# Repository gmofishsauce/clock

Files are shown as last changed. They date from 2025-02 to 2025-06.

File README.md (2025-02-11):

# Nixie tube clock with WiFi

This is a Nixie tube clock with IN-12 (axial view) Nixie tubes.
For nice packaging, the design is split into two boards. They
mount [at right angles](https://docs.google.com/presentation/d/11yNopbXGtAtQ4xKlA-b-B579JGvuL5Y8hJCB-doAy8I/edit?usp=sharing) using 96-pin Eurobus ("VME") connectors.

## Subdirectories:

- logic: logic (base board) with Arduino, drivers, power supply.
- display: display board with Nixie tube sockets
- proto: a prototype to check out the PCB footprints.

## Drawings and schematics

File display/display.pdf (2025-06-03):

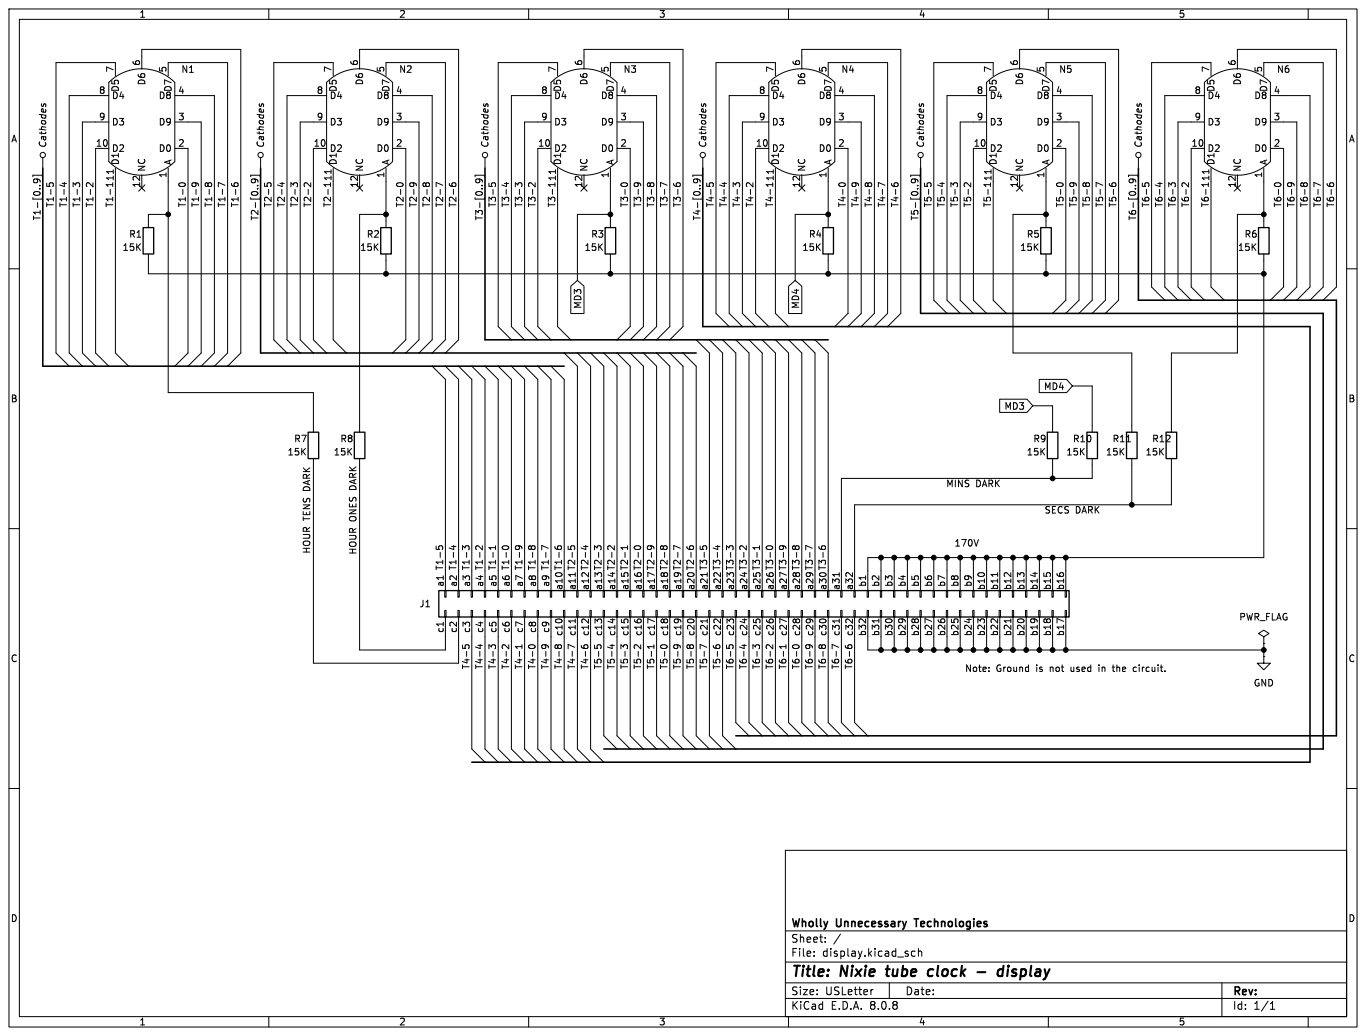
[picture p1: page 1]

Id: 1/1 Title: Nixie tube clock - display

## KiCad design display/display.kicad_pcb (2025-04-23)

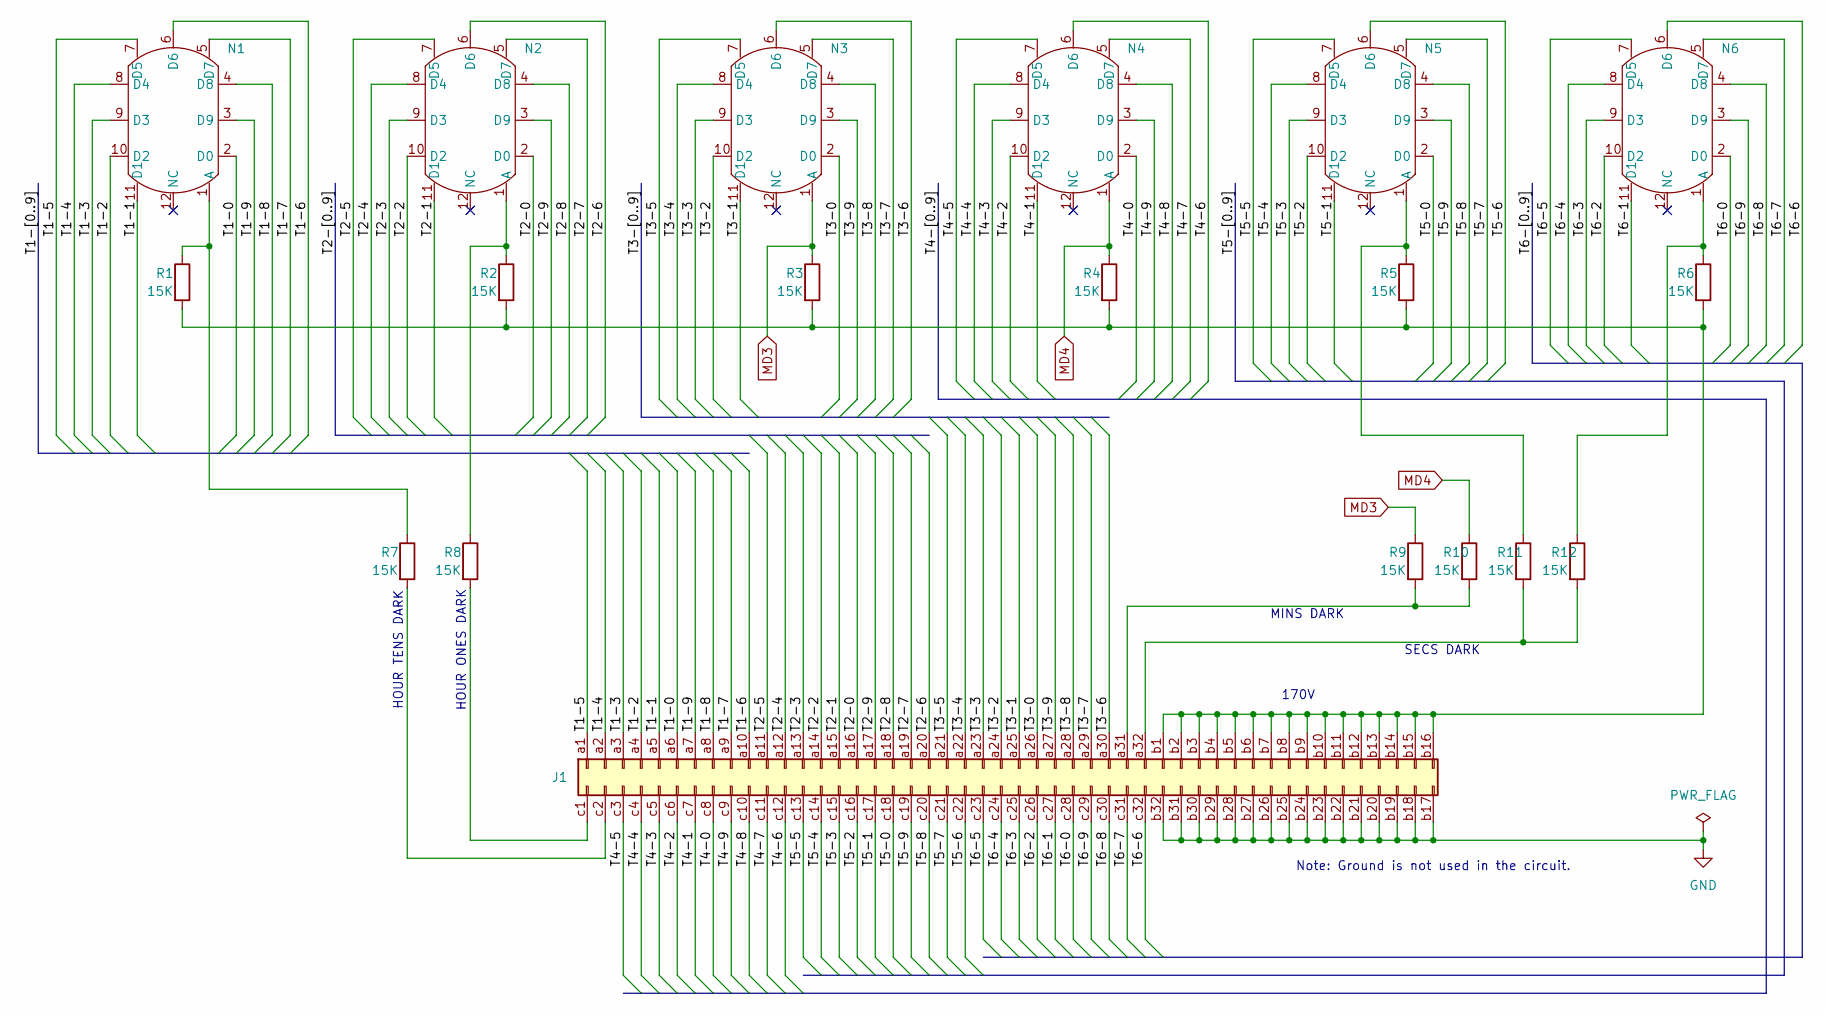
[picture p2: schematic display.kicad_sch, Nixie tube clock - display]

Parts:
J1: DIN41612_03x32_ABC; DIN41612_R_3x32_Female_Horizontal_THT
N1, N2, N3, N4, N5, N6: IN_12B_Socket
R1, R2, R3, R4, R5, R6, R7, R8, R9, R10, R11, R12: 15K; R_Box_L13.0mm_W4.0mm_P9.00mm

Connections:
/T1-0: J1.a6, N1.2 (D0)
/T1-1: J1.a5, N1.11 (D1)
/T1-2: J1.a4, N1.10 (D2)
/T1-3: J1.a3, N1.9 (D3)
/T1-4: J1.a2, N1.8 (D4)
/T1-5: J1.a1, N1.7 (D5)
/T1-6: J1.a10, N1.6 (D6)
/T1-7: J1.a9, N1.5 (D7)
/T1-8: J1.a8, N1.4 (D8)
/T1-9: J1.a7, N1.3 (D9)
/T2-0: J1.a16, N2.2 (D0)
/T2-1: J1.a15, N2.11 (D1)
/T2-2: J1.a14, N2.10 (D2)
/T2-3: J1.a13, N2.9 (D3)
/T2-4: J1.a12, N2.8 (D4)
/T2-5: J1.a11, N2.7 (D5)
/T2-6: J1.a20, N2.6 (D6)
/T2-7: J1.a19, N2.5 (D7)
/T2-8: J1.a18, N2.4 (D8)
/T2-9: J1.a17, N2.3 (D9)
/T3-0: J1.a26, N3.2 (D0)
/T3-1: J1.a25, N3.11 (D1)
/T3-2: J1.a24, N3.10 (D2)
/T3-3: J1.a23, N3.9 (D3)
/T3-4: J1.a22, N3.8 (D4)
/T3-5: J1.a21, N3.7 (D5)
/T3-6: J1.a30, N3.6 (D6)
/T3-7: J1.a29, N3.5 (D7)
/T3-8: J1.a28, N3.4 (D8)
/T3-9: J1.a27, N3.3 (D9)
/T4-0: J1.c8, N4.2 (D0)
/T4-1: J1.c7, N4.11 (D1)
/T4-2: J1.c6, N4.10 (D2)
/T4-3: J1.c5, N4.9 (D3)
/T4-4: J1.c4, N4.8 (D4)
/T4-5: J1.c3, N4.7 (D5)
/T4-6: J1.c12, N4.6 (D6)
/T4-7: J1.c11, N4.5 (D7)
/T4-8: J1.c10, N4.4 (D8)
/T4-9: J1.c9, N4.3 (D9)
/T5-0: J1.c18, N5.2 (D0)
/T5-1: J1.c17, N5.11 (D1)
/T5-2: J1.c16, N5.10 (D2)
/T5-3: J1.c15, N5.9 (D3)
/T5-4: J1.c14, N5.8 (D4)
/T5-5: J1.c13, N5.7 (D5)
/T5-6: J1.c22, N5.6 (D6)
/T5-7: J1.c21, N5.5 (D7)
/T5-8: J1.c20, N5.4 (D8)
/T5-9: J1.c19, N5.3 (D9)
/T6-0: J1.c28, N6.2 (D0)
/T6-1: J1.c27, N6.11 (D1)
/T6-2: J1.c26, N6.10 (D2)
/T6-3: J1.c25, N6.9 (D3)
/T6-4: J1.c24, N6.8 (D4)
/T6-5: J1.c23, N6.7 (D5)
/T6-6: J1.c32, N6.6 (D6)
/T6-7: J1.c31, N6.5 (D7)
/T6-8: J1.c30, N6.4 (D8)
/T6-9: J1.c29, N6.3 (D9)
GND: J1.b17, J1.b18, J1.b19, J1.b20, J1.b21, J1.b22, J1.b23, J1.b24, J1.b25, J1.b26, J1.b27, J1.b28, J1.b29, J1.b30, J1.b31, J1.b32
MD3: N3.1 (A), R3.1, R9.1
MD4: N4.1 (A), R4.1, R10.1
unnamed: J1.a31, R9.2, R10.2
unnamed: J1.a32, R11.2, R12.2
unnamed: J1.b1, J1.b2, J1.b3, J1.b4, J1.b5, J1.b6, J1.b7, J1.b8, J1.b9, J1.b10, J1.b11, J1.b12, J1.b13, J1.b14, J1.b15, J1.b16, R1.2, R2.2, R3.2, R4.2, R5.2, R6.2
unnamed: J1.c1, R8.2
unnamed: J1.c2, R7.2
unnamed: N1.1 (A), R1.1, R7.1
unnamed: N2.1 (A), R2.1, R8.1
unnamed: N5.1 (A), R5.1, R11.1
unnamed: N6.1 (A), R6.1, R12.1

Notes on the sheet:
Note: Ground is not used in the circuit.
MINS DARK
SECS DARK
HOUR ONES DARK
170V
HOUR TENS DARK

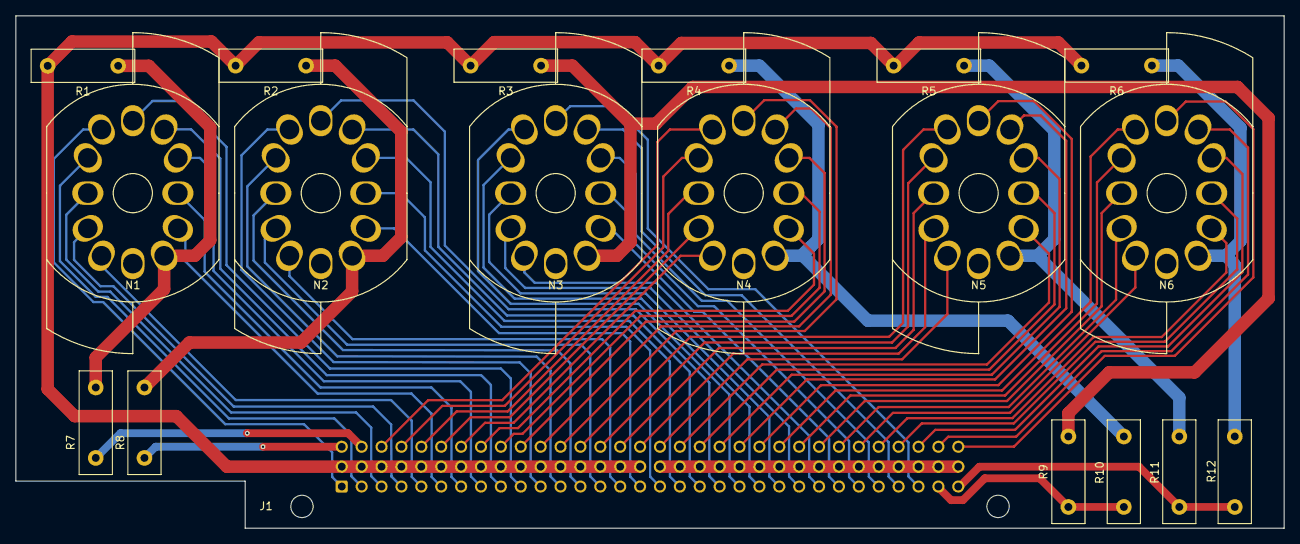
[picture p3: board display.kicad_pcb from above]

Board: 4 copper layers, 162.0 x 65.4 mm, 19 parts (1 on the bottom side), 72 nets.

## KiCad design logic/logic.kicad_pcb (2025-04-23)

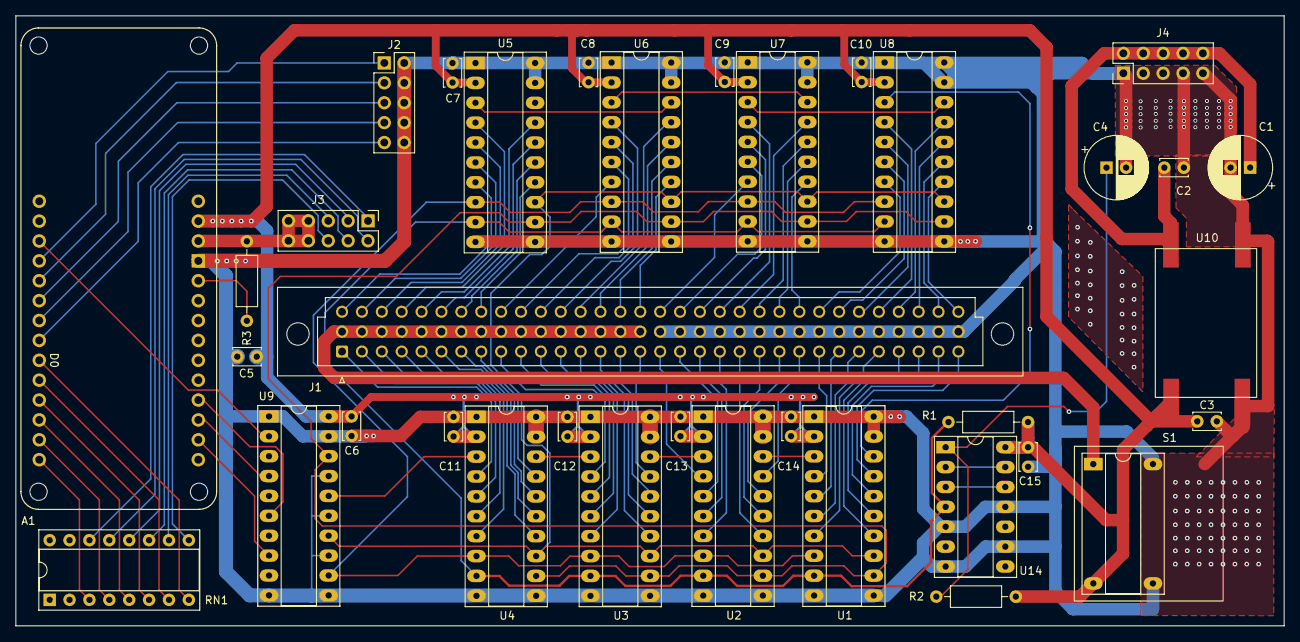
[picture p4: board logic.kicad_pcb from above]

Board: 4 copper layers, 162.0 x 77.9 mm, 36 parts (0 on the bottom side), 106 nets.

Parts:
A1: Arduino_MKR_WiFi_1010_Socket
C1, C4: C; CP_Radial_D8.0mm_P2.50mm
C2, C3, C5, C6, C7, C8, C9, C10, C11, C12, C13, C14, C15: C; C_Disc_D3.4mm_W2.1mm_P2.50mm
J1: DIN41612_03x32_ABC; DIN41612_R_3x32_Male_Vertical_THT
J2, J3, J4: Conn_02x05_Odd_Even; PinHeader_2x05_P2.54mm_Vertical
R1, R2, R3: R; R_Axial_DIN0207_L6.3mm_D2.5mm_P10.16mm_Horizontal
RN1: R_Pack08; DIP-16_W7.62mm_Socket
S1: NCH8200HV
U1, U2, U3, U4, U5, U6, U7, U8: TPIC6595; DIP-20_W7.62mm_Socket_LongPads
U9: 74HCT244; DIP-20_W7.62mm_Socket_LongPads
U10: TR4R7
U14: 74HC14; DIP-14_W7.62mm_Socket_LongPads

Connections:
/B1-0: J1.a25, U1.4 (DRAIN0)
/B1-1: J1.a26, U1.5 (DRAIN1)
/B1-2: J1.a27, U1.6 (DRAIN2)
/B1-3: J1.a28, U1.7 (DRAIN3)
/B1-4: J1.a29, U1.14 (DRAIN4)
/B1-5: J1.a30, U1.15 (DRAIN5)
/B1-6: J1.a31, U1.16 (DRAIN6)
/B1-7: J1.a32, U1.17 (DRAIN7)
/B2-0: J1.a17, U2.4 (DRAIN0)
/B2-1: J1.a18, U2.5 (DRAIN1)
/B2-2: J1.a19, U2.6 (DRAIN2)
/B2-3: J1.a20, U2.7 (DRAIN3)
/B2-4: J1.a21, U2.14 (DRAIN4)
/B2-5: J1.a22, U2.15 (DRAIN5)
/B2-6: J1.a23, U2.16 (DRAIN6)
/B2-7: J1.a24, U2.17 (DRAIN7)
/B3-0: J1.a9, U3.4 (DRAIN0)
/B3-1: J1.a10, U3.5 (DRAIN1)
/B3-2: J1.a11, U3.6 (DRAIN2)
/B3-3: J1.a12, U3.7 (DRAIN3)
/B3-4: J1.a13, U3.14 (DRAIN4)
/B3-5: J1.a14, U3.15 (DRAIN5)
/B3-6: J1.a15, U3.16 (DRAIN6)
/B3-7: J1.a16, U3.17 (DRAIN7)
/B4-0: J1.a1, U4.4 (DRAIN0)
/B4-1: J1.a2, U4.5 (DRAIN1)
/B4-2: J1.a3, U4.6 (DRAIN2)
/B4-3: J1.a4, U4.7 (DRAIN3)
/B4-4: J1.a5, U4.14 (DRAIN4)
/B4-5: J1.a6, U4.15 (DRAIN5)
/B4-6: J1.a7, U4.16 (DRAIN6)
/B4-7: J1.a8, U4.17 (DRAIN7)
/B5-0: J1.c1, U5.7 (DRAIN3)
/B5-1: J1.c2, U5.6 (DRAIN2)
/B5-2: J1.c3, U5.5 (DRAIN1)
/B5-3: J1.c4, U5.4 (DRAIN0)
/B5-4: J1.c5, U5.17 (DRAIN7)
/B5-5: J1.c6, U5.16 (DRAIN6)
/B5-6: J1.c7, U5.15 (DRAIN5)
/B5-7: J1.c8, U5.14 (DRAIN4)
/B6-0: J1.c9, U6.7 (DRAIN3)
/B6-1: J1.c10, U6.6 (DRAIN2)
/B6-2: J1.c11, U6.5 (DRAIN1)
/B6-3: J1.c12, U6.4 (DRAIN0)
/B6-4: J1.c13, U6.17 (DRAIN7)
/B6-5: J1.c14, U6.16 (DRAIN6)
/B6-6: J1.c15, U6.15 (DRAIN5)
/B6-7: J1.c16, U6.14 (DRAIN4)
/B7-0: J1.c17, U7.7 (DRAIN3)
/B7-1: J1.c18, U7.6 (DRAIN2)
/B7-2: J1.c19, U7.5 (DRAIN1)
/B7-3: J1.c20, U7.4 (DRAIN0)
/B7-4: J1.c21, U7.17 (DRAIN7)
/B7-5: J1.c22, U7.16 (DRAIN6)
/B7-6: J1.c23, U7.15 (DRAIN5)
/B7-7: J1.c24, U7.14 (DRAIN4)
/B8-0: J1.c25, U8.7 (DRAIN3)
/B8-1: J1.c26, U8.6 (DRAIN2)
/B8-2: J1.c27, U8.5 (DRAIN1)
/B8-3: J1.c28, U8.4 (DRAIN0)
/B8-4: J1.c29, U8.17 (DRAIN7)
/B8-5: J1.c30, U8.16 (DRAIN6)
/B8-6: J1.c31, U8.15 (DRAIN5)
/B8-7: J1.c32, U8.14 (DRAIN4)
/RCLK: U1.12 (RCLK), U2.12 (RCLK), U3.12 (RCLK), U4.12 (RCLK), U5.12 (RCLK), U6.12 (RCLK), U7.12 (RCLK), U8.12 (RCLK), U9.18 (O0a)
/SRCK: U1.13 (SRCK), U2.13 (SRCK), U3.13 (SRCK), U4.13 (SRCK), U5.13 (SRCK), U6.13 (SRCK), U7.13 (SRCK), U8.13 (SRCK), U9.14 (O2a)
/Sin1: U1.3 (SER_IN), U2.18 (SER_OUT)
/Sin2: U2.3 (SER_IN), U3.18 (SER_OUT)
/Sin3: U3.3 (SER_IN), U4.18 (SER_OUT)
/Sin4: U4.3 (SER_IN), U9.16 (O1a)
/Sin5: U5.3 (SER_IN), U6.18 (SER_OUT)
/Sin6: U6.3 (SER_IN), U7.18 (SER_OUT)
/Sin7: U7.3 (SER_IN), U8.18 (SER_OUT)
/Sin8: U1.18 (SER_OUT), U8.3 (SER_IN)
/~SRCLR3.3: A1.A1, U9.2 (I0a)
/~SRCLR: U1.8 (~SRCLR), U2.8 (~SRCLR), U3.8 (~SRCLR), U4.8 (~SRCLR), U5.8 (~SRCLR), U6.8 (~SRCLR), U7.8 (~SRCLR), U8.8 (~SRCLR), U9.12 (O3a)
GND: A1.GND, C1.2, C2.2, C3.2, C4.2, C5.2, C6.2, C7.2, C8.2, C9.2, C10.2, C11.2, C12.2, C13.2, C14.2, C15.2, J1.b17, J1.b18, J1.b19, J1.b20, J1.b21, J1.b22, J1.b23, J1.b24, J1.b25, J1.b26, J1.b27, J1.b28, J1.b29, J1.b30, J1.b31, J1.b32, J2.2, J2.4, J2.6, J2.8, J2.10, J4.1, J4.3, J4.5, J4.7, J4.9, S1.3 (LGND), S1.4 (PGND), U1.1 (PGND), U1.10 (PGND), U1.11 (PGND), U1.19 (LGND), U1.20 (PGND), U2.1 (PGND), U2.10 (PGND), U2.11 (PGND), U2.19 (LGND), U2.20 (PGND), U3.1 (PGND), U3.10 (PGND), U3.11 (PGND), U3.19 (LGND), U3.20 (PGND), U4.1 (PGND), U4.10 (PGND), U4.11 (PGND), U4.19 (LGND), U4.20 (PGND), U5.1 (PGND), U5.10 (PGND), U5.11 (PGND), U5.19 (LGND), U5.20 (PGND), U6.1 (PGND), U6.10 (PGND), U6.11 (PGND), U6.19 (LGND), U6.20 (PGND), U7.1 (PGND), U7.10 (PGND), U7.11 (PGND), U7.19 (LGND), U7.20 (PGND), U8.1 (PGND), U8.10 (PGND), U8.11 (PGND), U8.19 (LGND), U8.20 (PGND), U9.1 (OEa), U9.10 (GND), U9.11 (I0b), U9.13 (I1b), U9.15 (I2b), U9.17 (I3b), U9.19 (OEb), U10.3 (GND), U10.4 (IN-), U14.5, U14.7 (GND), U14.9, U14.11
unnamed: A1.D8 (D8_MOSI), U9.4 (I1a)
unnamed: A1.D9 (D9_SCK), U9.6 (I2a)
unnamed: A1.RST (RESET), R3.2
unnamed: C4.1, R2.2, U14.1
unnamed: A1.A2, J2.1
unnamed: A1.A3, J2.3
unnamed: A1.A4, J2.5
unnamed: A1.A5, J2.7
unnamed: A1.A6, J2.9
unnamed: J3.1, RN1.14 (R3.2)
unnamed: J3.2, RN1.13 (R4.2)
unnamed: J3.3, RN1.12 (R5.2)
unnamed: J3.4, RN1.11 (R6.2)
unnamed: J3.5, RN1.10 (R7.2)
unnamed: J3.6, RN1.9 (R8.2)
unnamed: C1.1, C2.1, J4.2, J4.4, J4.6, J4.8, J4.10, U10.1 (IN+)
unnamed: A1.D5, RN1.3 (R3.1)
unnamed: A1.D4, RN1.4 (R4.1)
unnamed: A1.D3, RN1.5 (R5.1)
unnamed: A1.D2, RN1.6 (R6.1)
unnamed: A1.D1, RN1.7 (R7.1)
unnamed: A1.D0, RN1.8 (R8.1)
unnamed: A1.D7, U9.8 (I3a)
unnamed: U14.3, U14.12
unnamed: U14.2, U14.13
POR: R1.2, U1.9 (~G), U2.9 (~G), U3.9 (~G), U4.9 (~G), U5.9 (~G), U6.9 (~G), U7.9 (~G), U8.9 (~G), U14.4
V3.3: A1.3V3 (3.3V), J3.7, J3.8, J3.9, J3.10, R3.1
V5.0: A1.VIN, C3.1, C5.1, C6.1, C7.1, C8.1, C9.1, C10.1, C11.1, C12.1, C13.1, C14.1, C15.1, R1.1, R2.1, S1.2 (LV_IN), U1.2 (VCC), U2.2 (VCC), U3.2 (VCC), U4.2 (VCC), U5.2 (VCC), U6.2 (VCC), U7.2 (VCC), U8.2 (VCC), U9.20 (VCC), U10.2 (5v), U14.14 (VCC)
V170: J1.b1, J1.b2, J1.b3, J1.b4, J1.b5, J1.b6, J1.b7, J1.b8, J1.b9, J1.b10, J1.b11, J1.b12, J1.b13, J1.b14, J1.b15, J1.b16, S1.1 (HV_OUT)

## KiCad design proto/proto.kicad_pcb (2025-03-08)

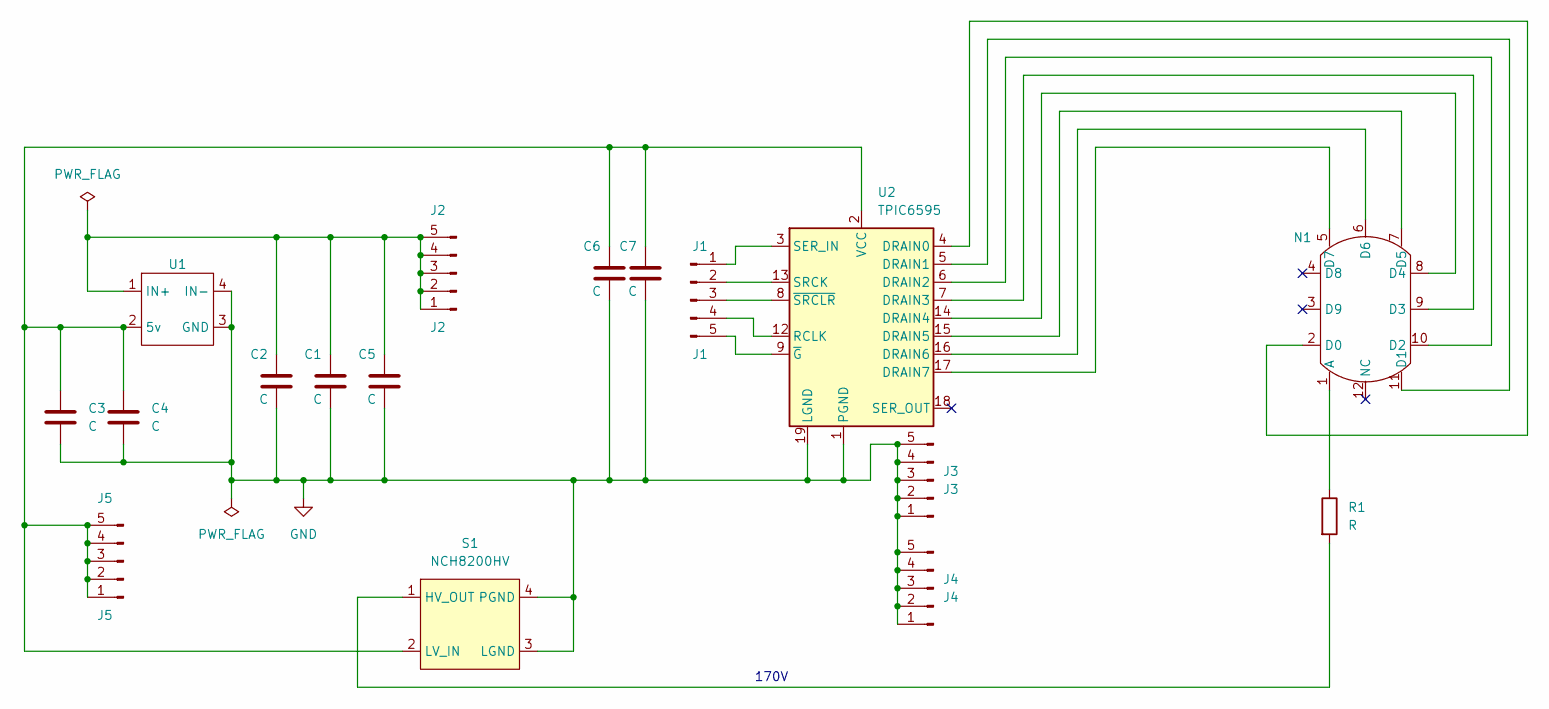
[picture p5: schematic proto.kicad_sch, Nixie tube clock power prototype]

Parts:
C1, C3: C; CP_Radial_D5.0mm_P2.50mm
C2, C4, C5, C6, C7: C; C_Disc_D3.0mm_W1.6mm_P2.50mm
J1: J1; PinHeader_1x05_P2.54mm_Vertical_SmallCourt
J2: J2; PinHeader_1x05_P2.54mm_Vertical_SmallCourt
J3: J3; PinHeader_1x05_P2.54mm_Vertical_SmallCourt
J4: J4; PinHeader_1x05_P2.54mm_Vertical_SmallCourt
J5: J5; PinHeader_1x05_P2.54mm_Vertical_SmallCourt
N1: IN_12B_Socket
R1: R; R_Axial_DIN0414_L11.9mm_D4.5mm_P15.24mm_Horizontal
S1: NCH8200HV
U1: TR4R7
U2: TPIC6595; DIP-20_W7.62mm_LongPads

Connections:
GND: C1.2, C2.2, C3.2, C4.2, C5.2, C6.2, C7.2, J3.1, J3.2, J3.3, J3.4, J3.5, J4.1, J4.2, J4.3, J4.4, J4.5, S1.3 (LGND), S1.4 (PGND), U1.3 (GND), U1.4 (IN-), U2.1 (PGND), U2.10 (PGND), U2.11 (PGND), U2.19 (LGND), U2.20 (PGND)
unnamed: J1.1, U2.3 (SER_IN)
unnamed: J1.2, U2.13 (SRCK)
unnamed: J1.3, U2.8 (~SRCLR)
unnamed: J1.4, U2.12 (RCLK)
unnamed: J1.5, U2.9 (~G)
unnamed: C1.1, C2.1, C5.1, J2.1, J2.2, J2.3, J2.4, J2.5, U1.1 (IN+)
unnamed: C3.1, C4.1, C6.1, C7.1, J5.1, J5.2, J5.3, J5.4, J5.5, S1.2 (LV_IN), U1.2 (5v), U2.2 (VCC)
unnamed: N1.1 (A), R1.1
unnamed: N1.2 (D0), U2.4 (DRAIN0)
unnamed: N1.11 (D1), U2.5 (DRAIN1)
unnamed: N1.10 (D2), U2.6 (DRAIN2)
unnamed: N1.9 (D3), U2.7 (DRAIN3)
unnamed: N1.8 (D4), U2.14 (DRAIN4)
unnamed: N1.7 (D5), U2.15 (DRAIN5)
unnamed: N1.6 (D6), U2.16 (DRAIN6)
unnamed: N1.5 (D7), U2.17 (DRAIN7)
unnamed: R1.2, S1.1 (HV_OUT)

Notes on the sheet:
170V

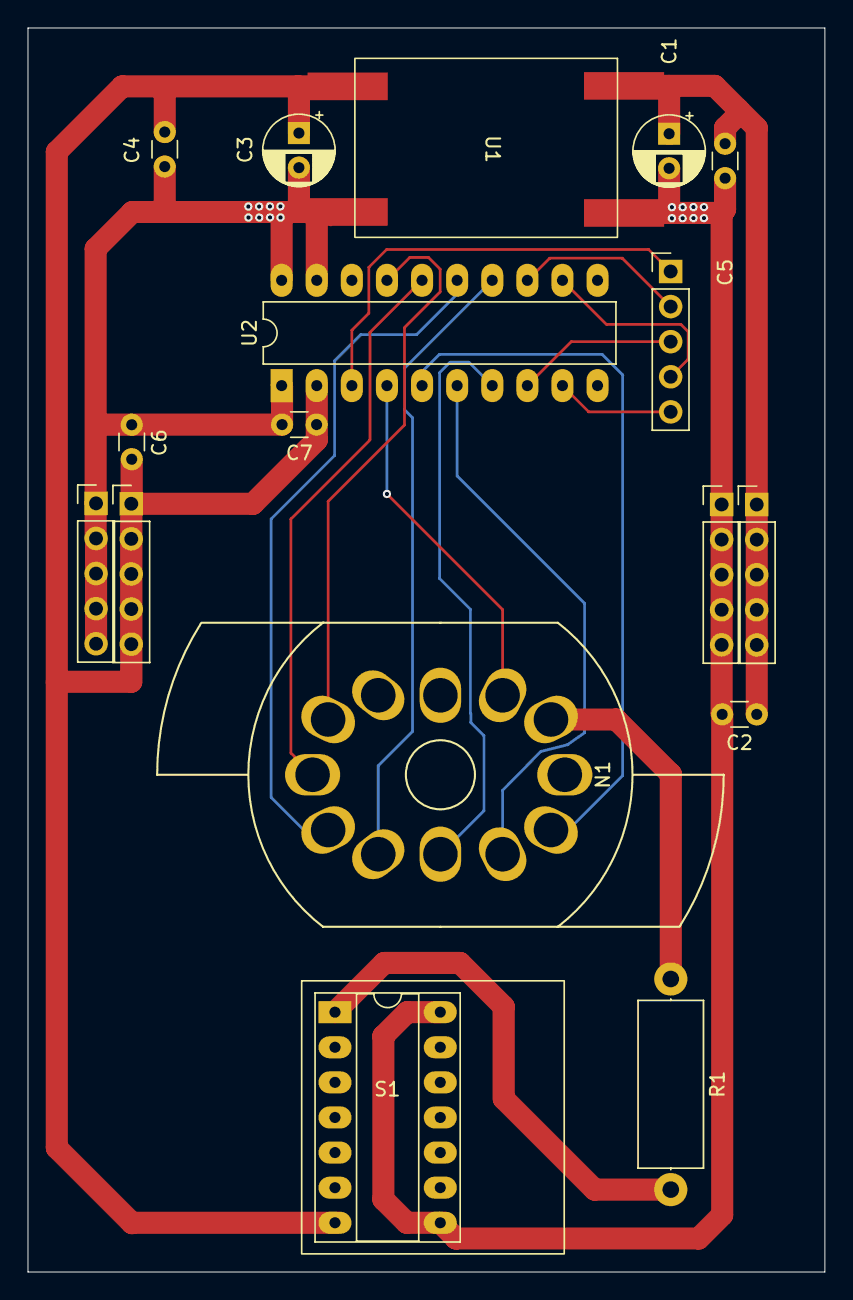
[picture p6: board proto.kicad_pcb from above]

Board: 4 copper layers, 57.7 x 90.0 mm, 17 parts (0 on the bottom side), 18 nets.

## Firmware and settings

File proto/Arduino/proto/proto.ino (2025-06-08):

#define COPI      8
#define SRCK      9
#define RCLK      A1
#define SRCLR     7

void clearSR() {
  Serial.println("SHIFT REGISTER CLEARED");
  digitalWrite(SRCLR, 0);
  digitalWrite(SRCLR, 1);
}

void clockSR() {
  digitalWrite(SRCK, 0);
  digitalWrite(SRCK, 1);
}

void clockRegister() {
  digitalWrite(RCLK, 0);
  digitalWrite(RCLK, 1);
}

void clockBit(int state) {
  digitalWrite(COPI, state);
  clockSR();
}

void setDefaults() {
  digitalWrite(SRCK, 1);
  digitalWrite(RCLK, 1);
  clearSR();
}

void printMillis(void) {
  long t = millis();
  printMillis(t);
}

void printMillis(long t) {
  char buffer[64];
  (void) sprintf(buffer, "running %ld", t);
  Serial.println(buffer);
}

void setup() {
  Serial.begin(115200);
  while (!Serial) {
    ;
  }
  Serial.println("start: ");
  printMillis();

  pinMode(RCLK, OUTPUT);
  pinMode(COPI, OUTPUT);
  pinMode(SRCK, OUTPUT);
  pinMode(SRCLR, OUTPUT);
  setDefaults();
}

byte buf[8];

#define B1  3
#define B2  2
#define B3  1
#define B4  0
#define B8  4
#define B7  5
#define B6  6
#define B5  7

#define BIT(n) (1<<n)

// Everything is MSB first. The argument is a byte stored in an int.
void byteOut(int b) {
  for (int i = 0; i < 8; ++i) {
    int state = ((b << i) & 0x80) ? HIGH : LOW;
    clockBit(state);
  }
}

void bufOut(byte *pb) {
  for (int i = 0; i < 8; ++i, ++pb) {
    byteOut(*pb);
  }
  clockRegister();
}

void loop() {
  for(;;) {
    printMillis();

    for(int i = 0; i < 8; ++i) { buf[i] = 0x00; }
    bufOut(buf);
    Serial.println("All bits off, including darkener bits");
    delay(8000);

    // FACT: B1-7 turns on the "9" filament in the seconds' units.
    // B1-6 turns on the "8" filament.
    for(int i = 0; i < 8; ++i) { buf[i] = 0x00; }
    buf[B1] = BIT(6);
    bufOut(buf);
    Serial.println("One filament lit in seconds tube");
    delay(8000);

    for(int i = 0; i < 8; ++i) { buf[i] = 0x00; }
    buf[B8] = 0x81;
    bufOut(buf);
    Serial.println("Seconds darkener enabled");
    delay(8000);
  }
}

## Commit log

2024-12-19 Initial commit. Schematic partially complete.
    [logic.kicad_pcb, logic.kicad_sch]
2024-12-20 Commit obsolete version before major revision
    [logic.kicad_sch]
2024-12-23 Temporary commit of circuit/ which will end up on Gitlab.
    [circuit.kicad_pcb, circuit.kicad_sch, display.kicad_sch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]
2025-01-04 Change to new 96-pin DIN-41612 schematic symbol in custom library
    [logic.kicad_pcb, logic.kicad_sch]
2025-01-05 Complete schematic. No DRC errors. Place components on PCB.
    [logic.kicad_pcb, logic.kicad_sch]
2025-01-05 Add footprint for HV supply to NixComp library and schematic.
    [logic.kicad_sch]
2025-01-08 Some changes to logic board. Begin schematic for display board.
    [display.kicad_pcb, display.kicad_sch, logic.kicad_sch]
2025-01-08 Complete rev 1 (alpha) schematics. Both pass DRC.
    [display.kicad_sch]
2025-01-08 Assign footprints for display and create PCB design
    [display.kicad_pcb, display.kicad_sch]
2025-01-11 Layout is ongoing
    [display.kicad_pcb, display.kicad_sch]
2025-01-11 Add footprint for NCH8200 high voltage supply
2025-01-11 Update schematic and PCB with HV supply footprint
    [logic.kicad_pcb, logic.kicad_sch]
2025-01-13 Additional minor tweaking
    [display.kicad_pcb, logic.kicad_pcb]
2025-01-29 LEDs connected by 10-pin connector now. 96 pin connector simplified.
    [logic.kicad_sch]
2025-01-30 Add low voltage supply to logic board
    [logic.kicad_pcb, logic.kicad_sch]
2025-02-02 Finally figure out how to attach nets to the NCH8200.
    [logic.kicad_pcb]
2025-02-11 Clean up symbol library references to be local to repo
    [display.kicad_pcb, display.kicad_sch]
2025-02-21 Commit older work
    [logic.kicad_pcb, logic.kicad_sch]
2025-02-21 Fix a problem with R1 on PCB
    [logic.kicad_pcb]
2025-02-21 Add Nixie socket to NixComp lib and update PCB
    [display.kicad_pcb, display.kicad_sch]
2025-02-21 Update libraries, schematic, and layout with buck converter
    [logic.kicad_pcb, logic.kicad_sch]
2025-02-21 Start prototype
    [proto.kicad_pcb, proto.kicad_sch]
2025-02-23 Ongoing development of prototype, symbols, footprints, and logic schematic
    [logic.kicad_sch, proto.kicad_pcb, proto.kicad_sch]
2025-02-25 Add footprint for socketed HV supply. Add R1 which was forgotten. Revise layout for significantly better density.
    [proto.kicad_pcb, proto.kicad_sch]
2025-02-26 Ongoing development
    [proto.kicad_pcb, proto.kicad_sch]
2025-02-26 Improve footprint for pin connectors and align four power and ground connectors (I hope)
    [proto.kicad_pcb, proto.kicad_sch]
2025-02-26 Ongoing development. Add ground vias.
    [proto.kicad_pcb, proto.kicad_sch]
2025-02-27 Equivalent of code complete on the proto board
    [proto.kicad_pcb]
2025-02-27 Completely revise high voltage converter footprint and circuit du to previous errors. Generate Gerbers. Some issues remain.
    [proto-B_Cu.gbr, proto-B_Mask.gbr, proto-B_Silkscreen.gbr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]
2025-03-08 Review and regenerate Gerbers.
    [proto-B_Cu.gbr, proto-B_Mask.gbr, proto-B_Silkscreen.gbr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]
2025-03-29 Prototype development in progress
2025-03-29 Prototype works now
2025-03-30 Non-working SPI library code
2025-04-08 Begin incorporating feedback from prototype. Checkpoint.
    [Logic-overflow.kicad_sch, logic.kicad_sch]
2025-04-09 Complete schematic and begin logic board layout.
    [Logic-overflow.kicad_sch, logic.kicad_pcb, logic.kicad_sch]
2025-04-10 Ongoing development. Add shunt resistors to display board.
    [Logic-overflow.kicad_sch, display.kicad_pcb, display.kicad_sch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]
2025-04-18 Proposed final display board positioning
    [display.kicad_pcb, display.kicad_sch, logic.kicad_pcb]
2025-04-18 Ongoing layout work on logic board.
    [display.kicad_pcb, logic.kicad_pcb]
2025-04-19 Tenatively, all parts in final positions
    [display.kicad_pcb, logic.kicad_pcb]
2025-04-19 Schematic corrected and display board is partially routed
    [display.kicad_pcb, display.kicad_sch]
2025-04-20 Display board is completely routed
    [display.kicad_pcb]
2025-04-20 Minor corrections and evaluate DRC warnings
    [display.kicad_pcb]
2025-04-20 Minor cleanups and generate fabrication outputs (Gerbers)
    [display-B_Cu.gbr, display-B_Mask.gbr, display-B_Paste.gbr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]
2025-04-20 Improve 3D model for prototype fab purposes
    [display.kicad_pcb]
2025-04-21 Ongoing development - logic board routing
    [logic.kicad_pcb, logic.kicad_sch]
2025-04-21 Ongoing development of logic board.
    [logic.kicad_pcb, logic.kicad_sch]
2025-04-22 Logic board is mostly routed. Changes to schematic for routing.
    [logic.kicad_pcb, logic.kicad_sch]
2025-04-22 Routing is complete. Validation and checking begins.
    [logic.kicad_pcb]
2025-04-22 DRC warnings evaluated
    [logic.kicad_pcb]
2025-04-23 Minor fussing and run DRC. Generate Gerbers and drill files.
    [logic-B_Cu.gbr, logic-B_Mask.gbr, logic-B_Paste.gbr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]
2025-04-23 Enlage notch in display board and minor fussing. New Gerbers.
    [display-B_Cu.gbr, display-B_Mask.gbr, display-B_Paste.gbr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]
2025-06-03 Update Arduino test code to clock boards and plot display schematic as a PDF.
